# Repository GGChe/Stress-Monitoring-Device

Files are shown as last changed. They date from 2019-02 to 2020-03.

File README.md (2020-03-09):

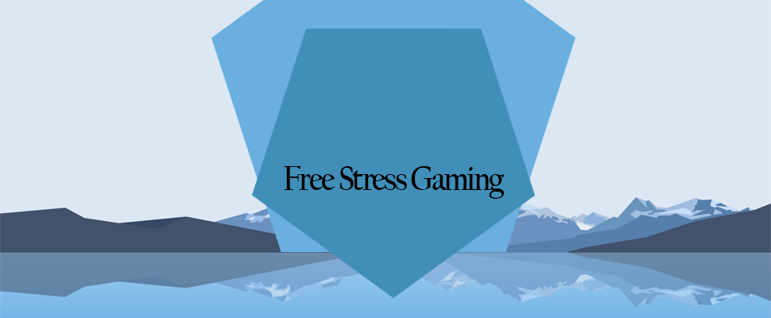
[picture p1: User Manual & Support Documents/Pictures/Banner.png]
StressFree.org Banner





# Welcome to FreeStressGame's open source Project!

Our tream provides an open-source real time embedded project based on the development of a real time biomedical device which aim is to monitor the stress level of a videogame player. This project is open source and anyone is invited to contribute freely sharing all your tips and modifications

## Table of Contents

* [Introduction](#introduction)
* [Methodology](#methodology)
* [Required Components](#required-components)
* [System Manual](#system-manual)
* [Found a Bug](#found-a-bug)
* [Contributing](#contributing)
* [Pubilcation](#publication)
* [SNS](#sns)
* [License](#lisence)

### Introduction

According to the World Health Organisation, mental disorders are a main topic in global health, specially because one in four people in the world will be affected by mental or neurological disorders at some point in their lives. It is estimated that more that 450 million people are currently suffering from such disorders, placing this risk to the top of all the ill-health's causes and disability worldwide. The main mental disorder is depression, and in many situations it is caused by stress. Nowadays, stress is a risk that every person need to face in some point of the day, like work, house, friends, etc. 

There is evidence available that supports the fact that the stress is one of the main triggers of depression. More in detail , such evidence shows that depression can stem from chronic overstimulation of the body's hypothalamic-pituitary-adrenal axis, which produces cortisol in humans. However, while adults can face the stress with therapy and different skills, children are a very enthreaten sector of the population that does not own skills against that. 

With the mentioned before, we can imagine that one of the most risky situations for a child are videogames where we set an unprepared person against a stressfull and addictive situation, causing severe damage on the child. 

Then, this project constitutes a reliable and attractive solution for parents, therapists and adults that want to monitor and control the stress status of the player.

### Methodology
#### [HeartBeat Detection]
The heartbeat measurement technology that we chose for this project is the photopletismography. 
This technique is based on the use of a photodiodethat emits a light pulse in a specific wavelength which, after passing by the blood vessel, the wavelength signal captured by the photosensor changes.  

OUTLINE

According to that change, we can determine whether a pulse of blood has passed in a specific time, depending on our sampling rate.  

#### [Stress Recognition] 
Once the signal is taken, it is carried to the raspberry Pi using a proper wirebased connection to avoid any unwanted interaction with other signals and for a better performance of the device.  
Then, the Raspberry PI will process the data in real time and, at the same time, it will do a basic threshold based control for deciding whether the person is under stress or not. When this process recognize the stress, it makes beep sound for warning. 



### Required Components 
The device consists of the next components:
- Raspberry Pi 3 B+
- PCB adaptor: 
  * 2 X 2Kohm SMD resistors
- Wrist sensor:
  * VEML6030 Light sensor 
  * 1 X IR LED
  * 1 X 1 Kohm SMD resistor 
  * 1 X 10 Kohm SMD resistor
  * 1 X 1000 nF SMD capasitor 
- Piezo Buzzer
- RJ45 Cable
- Finger / Band type case for Wrist sensor
- Raspberry Pi case 

All circuit schematics / PCB Eagle files/ 3D Solidworks files are included in UPLOADED DOCUMENTS. 

### System Description 

#### Hardware section 
In this section you will find useful information of how to replicate our project. Given the components listed before, you need to print the pcb, which files and more deep information is shown in the PCB folder.  

OUTLINE
pin outline
* Connect PCB adaptor with Wrist sensor by RJ45 cable
* Connect PCB adaptor pins with Raspberry Pi pins as shown in below table 

<p align="center">

 
<p align="center">


#### Software section

##### Software setting 
To build our program in your Pi, you need to follow some steps.  

```
sudo apt-get update

git clone https://github.com/GGChe/Stress_Controller_Device
```
You would need to update and install the libraries of PHP5.6, Apache2 and compilers if your are working on a vanilla version of the OS.

```
sudo apt-get install php5.6

sudo apt-get install apache2

sudo apt-get install g++
```
If you have any problem installing php5.6 in Raspbian, cause it is not very well supported, follow this guide:
https://unnikked.ga/how-to-install-php-5-6-on-a-raspberry-pi-2-5fd93879cb14

##### Driver 
We developed a driver for the VEML6030 sensor, that uses I2C communication protocol, using the data obtained from the link below. The driver given in that project was initially prepared for Arduino but we had to modify it completely to make it run in every system using a proper c++ code.

[Mbed VEML6030 Driver](https://os.mbed.com/teams/MSS/code/VEML6030/)

##### Compilation from source

To compile the whole code, you only need to go to the code's folder and type on the terminal

```
cmake .

make 

sudo ./StressC.out
```

To run the program from the boot of the system

```
sudo nano /etc/rc.local

```

And then, write before "exit 0" the following scrypt:

```
sudo ./PATH/StressC.out

```

### Found a bug?

Bugs can be reported at: https://github.com/GGChe/Stress_Controller_Device/issues

Please try the latest release build before reporting, be sure to also include any logs or steps to reproduce you may have, as well as your Forge version, and whether or not you are using a third party loader such as Cauldron. When submitting logs please use a service such as Pastebin, do not paste the log directly into the issue.

### Contributing

Ahmed Elmogamer 
* Main role: Software Engineer 
* Specific tasks 
  : Coding the main program and making sensors' driver.  

Daewon Jung  
* Main role: Mechanical Engineer 
* Specific tasks 
  : Designing cases, assist making PCB and Promotion. 
  
Gabriel Galeote Checa 
* Main role: Electronic Engineer 
* Specific tasks 
  : Designing PCB and Website architecture development, Fabrication and Soldering of the PCB. 
  
### Publication
Check our publication in Hackaday.

[](https://hackaday.io/project/164972-free-stress-gaming)

### SNS 
In our socialmedia you can find some demos and video explanations of how the system works. 

[](https://www.youtube.com/channel/UC1Y8QuR_0B8nRpyRaub2-ag)

[](https://www.instagram.com/free_stress_gaming/)

Check our two youtube videos explaining how the system works!
- https://www.youtube.com/watch?v=JRjO4hhqV6E
- https://www.youtube.com/watch?v=9uvpTM_b6e0&t=2s
### Credits

This project used the current driver uploaded in mbed for other purposes, we fixed some errors for the VEML6030 use in RPI and we had to recode some sections of the driver.

We also wannt to thanks our mate Cheng who was really helpful in the lab.

### License

The MIT License

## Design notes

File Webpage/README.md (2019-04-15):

# Website

## How does the webpage works?

We have developed a webpage architecture that is going to be the configuration interface between the user and the device. By login in the website and using the resources available in it the user is able to modify the parameters of their profile by the proposed calibration. 

The webpage main feature is to initialise the device and all the configuration needed for that as well as identify the user too have more than one user on the same device. Thus, if we load one user, we will be using that user all the time until we connect the device to internet and we change the user to other one.

The methodology is the following one:

- The first time you enter in the webpage you would need to signup. That will automatically generate a "login.txt" file on the /var/www/html/Project folder of the RPI. From here, all the files generated will be storaged on the same folder.

- Once the user is created and registered, the webpage will 
create an "user.txt" where it will set the user that is already registered.

- The first time that a user is signed up, it will appear the calibration webpage that is going to interact with the RPI to measure the Heart Rate Average of the user during the tasks required. 

- After the calibration, that can be done only the first time you log in or in your profile page, we go to the session webpage. In this webpage you have the possibility of recalibrate the sensor. If not, we go to the Session webpage.

- In the Session webpage, we can manually run the sensor by using the button provided.

That is everything! There you have a demo video of how to use the webpage architecture created!

[](https://www.youtube.com/watch?v=9uvpTM_b6e0&t=1s)

## How to install the webpage files

First, check that you have the correct packages for running php and apache server. For that, run the next commands on the terminal:

```
sudo apt-get update

sudo apt-get install apache 2
```

If you are using raspbian, you need to find the right package for php5.6 that is not really supported in Raspbian. Follow the next webpage steps to install it properly:

- https://unnikked.ga/how-to-install-php-5-6-on-a-raspberry-pi-2-5fd93879cb1

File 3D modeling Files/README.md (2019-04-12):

## 3D modeling cases for Strerss Controller 
To consider about the product's usability, PCB and Raspberry Pi cases are desinged by 'Solid Works', and rendered by 'KeyShot8'.  

## PCB_CASE
Depend on the user's preference, 'Watch type' or 'Finger type' case can be chosen for Sensor PCB. 

* Watch Type Case
<p align="center">
  
</p>
<p align="center">
  
</p>

* Finger Type Case
<p align="center">
  
</p>

## Raspberry-Pi CASE - Top 
Top case is desinged by below criteria: 
* This case should have enough holes for cooling.  
* This case should have appealing design for promotion 

<p align="center">
  
</p>
<p align="center">
  
</p>

## Raspberry-Pi CASE - Bottom 
Bottom case should be considered about ports for 'power cable' and 'SD-card'. 

<p align="center">
  
</p>

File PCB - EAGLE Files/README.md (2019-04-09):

# Electronic Design

This project consists of 2 main Printec Circuit Boards (PCB)pcbs: RPI adaptor and Sensor PCb.

The feature of the RPI adaptor pcb is to connect the correct RPI pines to the sensor circuit that we are using. We need to guide all the signal through a RJ45 cable that is going to the sensor pcb. Thus, it is need to adapt and guide signal in the correct order. 

The pcbs are shown below:
<p align="center">


<p align="center">


All the components that we are using on the PCB are Surface Mount Devices (SMD) and therefore, we should need a reflow oven to solder them, even though youu can solder everything by hang if you are skilled enough.

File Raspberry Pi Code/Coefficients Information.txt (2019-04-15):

The coefficients used were produced by a python code that utilized:

signal.firwin(801, [0.2, 10], pass_zero = 0, fs = 200)

This produces coefficients with the following specifications:

Taps: 801
lower frequency: 0.2 Hz
High frequency: 10 Hz
type of filter: Band Pass
Frequency: 200 Hz

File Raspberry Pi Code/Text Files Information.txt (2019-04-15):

An explanation of the text files:

status.txt:

0 - if the user is on the log in page
1 - if the user enters the Session page
2 - if the user enters the Sign up

username.txt:

Ahmed - has the current username being used whether when logged in or during configuration

userdata.txt:

Ahmed/23/43/13
Gabri/34/53/23
Daewon/43/54/54

Has a list of all the users and their rest, run and stress. 
These values have to be of 2 digits.

exit.txt:

0 - stay in current page
1 - return to main menu

session.txt:

After the user logs in

0 - do not read the sensor
1 - read the sensor and detect stress

config.txt:

During configuration

0 - do not read and wait for user's confirmation
1 - read and calculate required average "rest or run"

white.txt:

used by RPI to output the detected white signals

eventlog.txt:

Writes the log of all the stress events recorded.

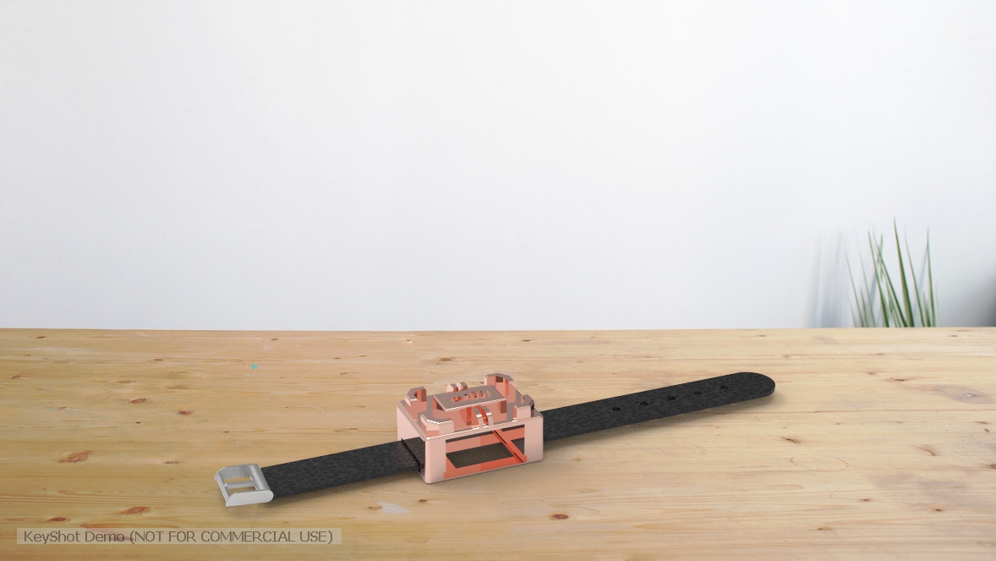
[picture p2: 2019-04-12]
3D modeling Files/keyshot/PCBcase1.jpg

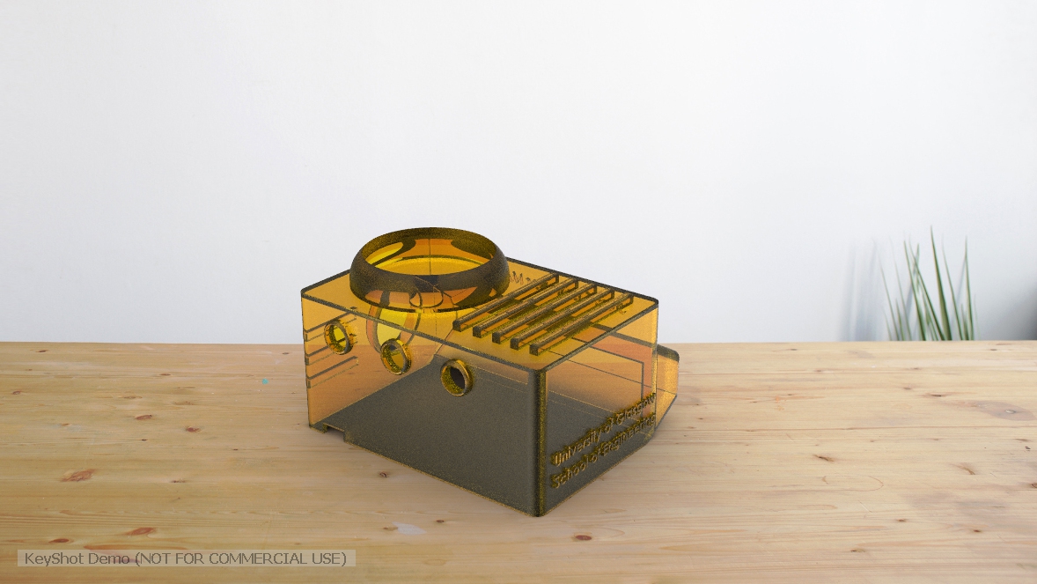
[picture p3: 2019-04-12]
3D modeling Files/keyshot/Topcase2.jpg

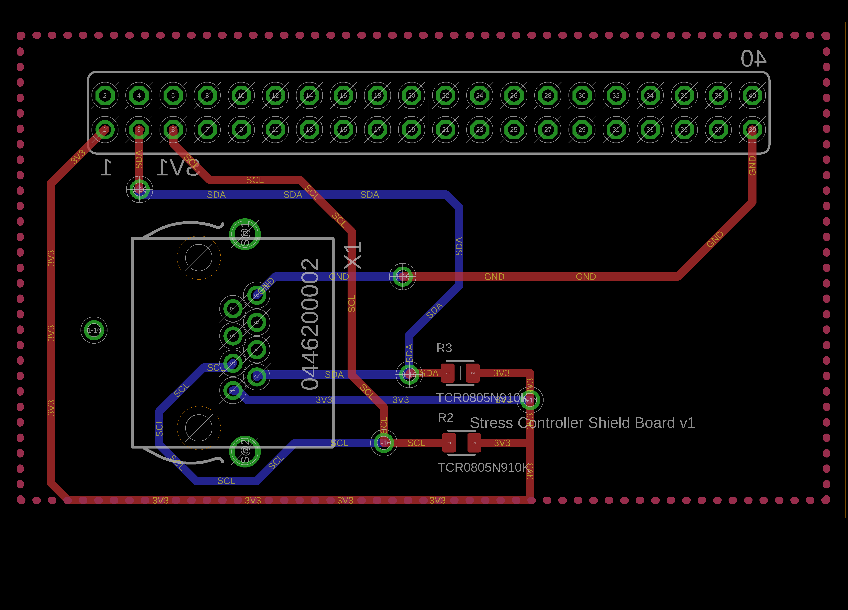
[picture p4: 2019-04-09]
PCB - EAGLE Files/Models/PCB_RPI/RPI-PCB.png

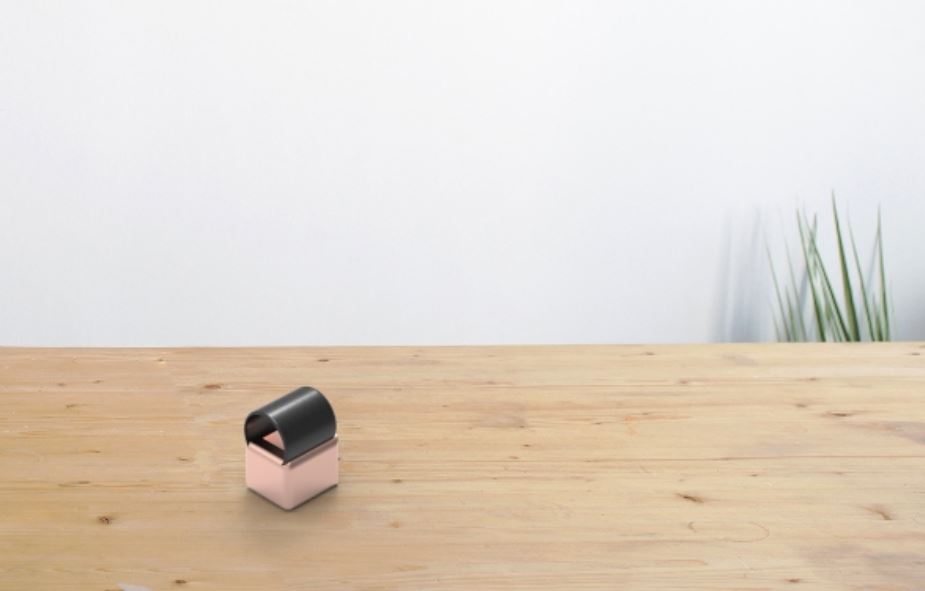
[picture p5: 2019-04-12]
3D modeling Files/keyshot/Fingertype.JPG

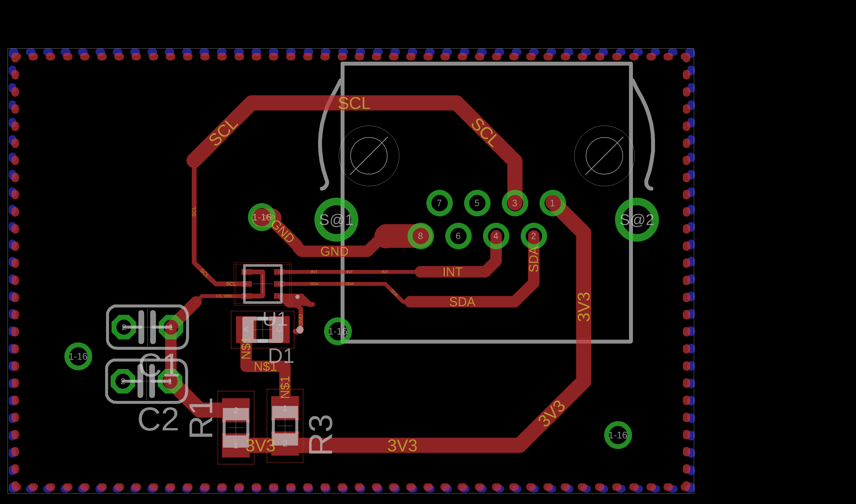
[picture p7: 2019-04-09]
PCB - EAGLE Files/Models/PCB_Sensor/SENSOR-PCB.png

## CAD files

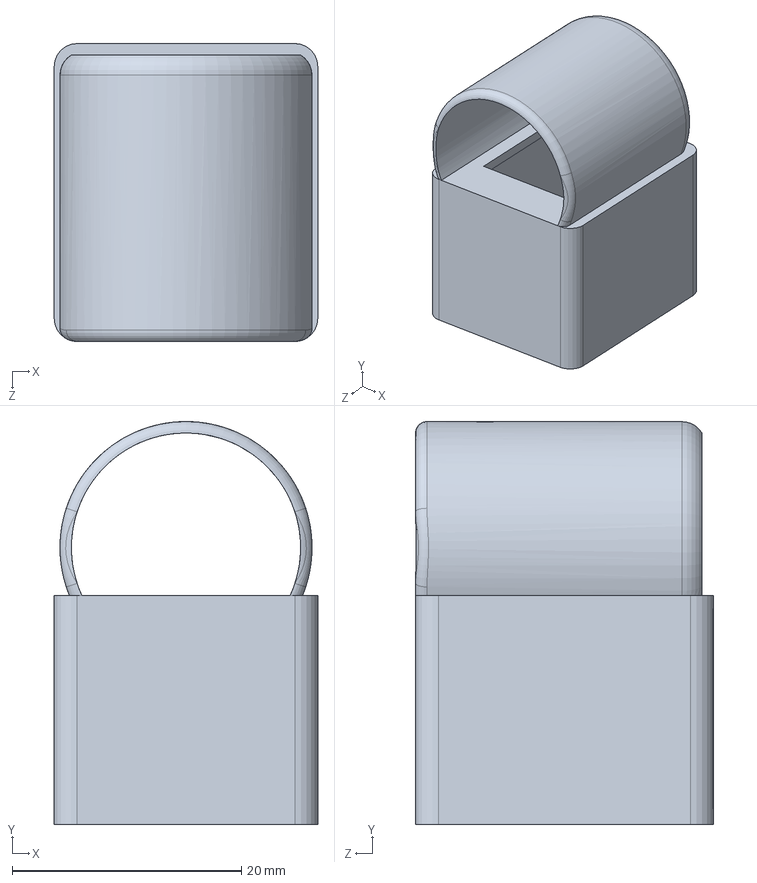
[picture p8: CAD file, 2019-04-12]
3D modeling Files/Finger_Type_CASE.SLDPRT
23.0 x 35.2 x 26.0 mm

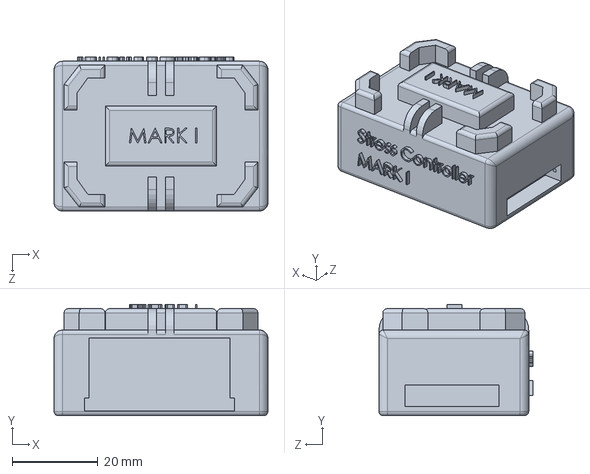
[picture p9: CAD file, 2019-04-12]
3D modeling Files/Watch_Type_CASE.SLDPRT
50.0 x 26.0 x 36.0 mm

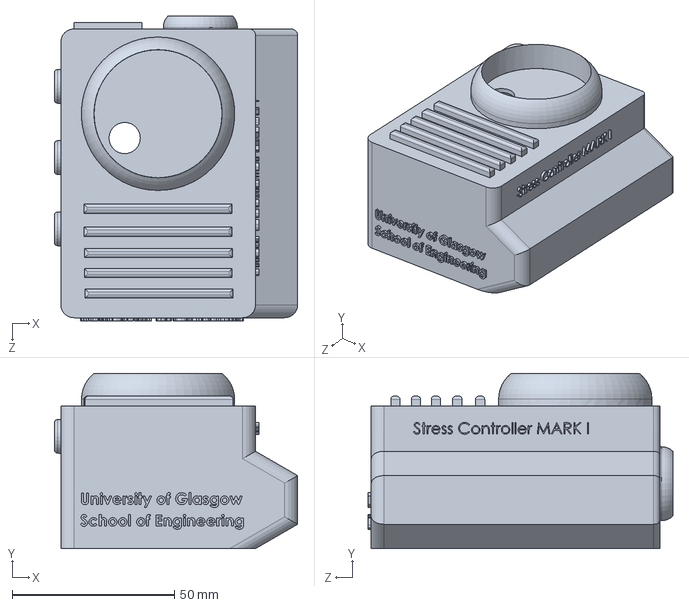
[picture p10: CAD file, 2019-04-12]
3D modeling Files/Raspberry_Pi_TOP CASE.SLDPRT
75.0 x 54.0 x 94.0 mm

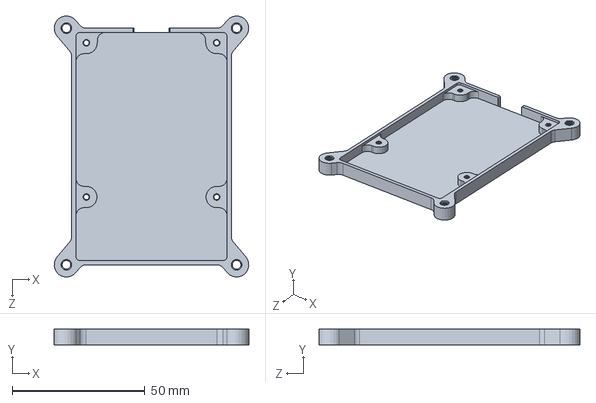
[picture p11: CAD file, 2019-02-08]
3D modeling Files/BOTTOM CASE.SLDPRT
73.2 x 6.01 x 98.2 mm

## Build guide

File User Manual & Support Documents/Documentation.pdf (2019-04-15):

## Stress Controller Device C++ Code

Generated by Doxygen 1.8.15

i

1 Hierarchical Index | 1
2 Class Index | 3
3 File Index | 5
4 Class Documentation | 7

Generated by Doxygen

ii

5 File Documentation | 19

iii

iv

Index | 33

# Chapter 1

# Hierarchical Index

## 1.1 Class Hierarchy

This inheritance list is sorted roughly, but not completely, alphabetically:

CppTimer | 7
ObtainData | 12
Fir1 | | 8
VEML6030rpi | | 13

### 2 Hierarchical Index

# Chapter 2

# Class Index

## 2.1 Class List

Here are the classes, structs, unions and interfaces with brief descriptions:

### 4 Class Index

# Chapter 3

# File Index

## 3.1 File List

Here is a list of all files with brief descriptions:

### 6 File Index

# Chapter 4

# Class Documentation

## 4.1 CppTimer Class Reference

#include <CppTimer.h>

Inheritance diagram for CppTimer:

CppTimer

ObtainData

Public Member Functions

- CppTimer ()
- virtual ∼CppTimer ()
- void start (long nanosecs)
- virtual void timerEvent ()=0

### 4.1.1 Constructor & Destructor Documentation

### 4.1.1.1 CppTimer()

CppTimer::CppTimer ( ) [inline]

4.1.1.2 ∼CppTimer()

virtual CppTimer::∼CppTimer ( ) [inline], [virtual]

### 8 Class Documentation

### 4.1.2 Member Function Documentation

### 4.1.2.1 start()

void CppTimer::start (

long nanosecs ) [inline]

### 4.1.2.2 timerEvent()

virtual void CppTimer::timerEvent ( ) [pure virtual]

The documentation for this class was generated from the following file:

- C:/Users/Mufasa/Desktop/123/Final_V3/CppTimer.h

## 4.2 Fir1 Class Reference

#include <Fir1.h>

Public Member Functions

- template<unsigned nTaps>
Fir1 (const double(&_coefficients)[nTaps])
- Fir1 (double ∗coefficients, unsigned number_of_taps)
- Fir1 (const char ∗coeffFile, unsigned number_of_taps=0)
- Fir1 (unsigned number_of_taps)
- ∼Fir1 ()
- double filter (double input)
- void lms_update (double error)
- void setLearningRate (double _mu)
- double getLearningRate ()
- void reset ()
- void zeroCoeff ()
- unsigned getTaps ()
- double getTapInputPower ()

### 4.2.1 Detailed Description

Finite impulse response filter. The precision is double. It takes as an input a file with coefficients or an double array.

4.2 Fir1 Class Reference | 9

### 4.2.2 Constructor & Destructor Documentation

### 4.2.2.1 Fir1() [1/4]

template<unsigned nTaps>

Fir1::Fir1 (

const double(&) _coefficients[nTaps] ) [inline]

Coefficients as a const double array. Because the array is const the number of taps is identical to the length of the array.

### 10 Class Documentation

Parameters

_coefficients A const double array with the impulse response.

### 4.2.2.2 Fir1() [2/4]

Fir1::Fir1 (

double ∗ coefficients,

unsigned number_of_taps )

Coefficients as a (non-constant-) double array where the length needs to be specified.

Parameters

coefficients | Coefficients as double array.
number_of_taps | Number of taps (needs to match the number of coefficients

### 4.2.2.3 Fir1() [3/4]

Fir1::Fir1 (

const char ∗ coeffFile,

unsigned number_of_taps = 0 )

Coefficients as a text file (for example from Python) The number of taps is automatically detected when the taps are kept zero.

Parameters

coeffFile | Patht to textfile where every line contains one coefficient
number_of_taps | Number of taps (0 = autodetect)

### 4.2.2.4 Fir1() [4/4]

Fir1::Fir1 (

unsigned number_of_taps )

Inits all coefficients and the buffer to zero

This is useful for adaptive filters where we start with zero valued coefficients.

4.2 Fir1 Class Reference | 11

4.2.2.5 ∼Fir1()

Fir1::∼Fir1 ( )

Releases the coefficients and buffer.

### 4.2.3 Member Function Documentation

### 4.2.3.1 filter()

double Fir1::filter (

double input )

The actual filter function operation: it receives one sample and returns one sample.

Parameters

input The input sample.

### 4.2.3.2 getLearningRate()

double Fir1::getLearningRate ( ) [inline]

Getting the learning rate for the adaptive filter.

### 4.2.3.3 getTapInputPower()

double Fir1::getTapInputPower ( )

Returns the power of the of the buffer content:

sum_k buffer[k]∧2 which is needed to implement a normalised LMS algorithm.

### 4.2.3.4 getTaps()

unsigned Fir1::getTaps ( ) [inline]

Returns the number of taps.

### 4.2.3.5 lms_update()

void Fir1::lms_update (

double error )

LMS adaptive filter weight update:

Every filter coefficient is updated with: w_k(n+1) = w_k(n) + learning_rate ∗ buffer_k(n) ∗ error(n)

### 12 Class Documentation

Parameters

error Is the term error(n), the error which adjusts the FIR conefficients.

### 4.2.3.6 reset()

void Fir1::reset ( )

Resets the buffer (but not the coefficients)

### 4.2.3.7 setLearningRate()

void Fir1::setLearningRate (

double _mu ) [inline]

Setting the learning rate for the adaptive filter.

Parameters

_mu The learning rate (i.e. rate of the change by the error signal)

### 4.2.3.8 zeroCoeff()

void Fir1::zeroCoeff ( )

Sets all coefficients to zero

The documentation for this class was generated from the following files:

- C:/Users/Mufasa/Desktop/123/Final_V3/Fir1.h
- C:/Users/Mufasa/Desktop/123/Final_V3/Fir1.cpp

## 4.3 ObtainData Class Reference

Inheritance diagram for ObtainData:

ObtainData

CppTimer

4.4 VEML6030rpi Class Reference | 13

Additional Inherited Members

The documentation for this class was generated from the following file:

- C:/Users/Mufasa/Desktop/123/Final_V3/StressController.cpp

## 4.4 VEML6030rpi Class Reference

#include <VEML6030rpi.h>

Public Member Functions

- VEML6030rpi ()
- virtual ∼VEML6030rpi ()
- void init (uint8_t _ADR)
- void setALS (uint16_t cmd)
- void setALS_WH (uint16_t wh)
- void setALS_WL (uint16_t wl)
- uint8_t SetIntTime (uint16_t TimeBits)
- uint8_t SetGain (uint16_t GainVal)
- uint16_t getALS (void)
- uint16_t getWhite (void)
- uint16_t getALS_INT (void)
- unsigned int IntTime2Bits (unsigned int Time)
- uint16_t Gain2Bits (float GainVal)
- void powerSaving (uint16_t ps)
- uint8_t Shutdown (void)
- uint8_t PowerOn (void)
- void SetResolution (float Gain, float IntTime)
- void AutoSet (void)

Public Attributes

- uint16_t als
- uint16_t white
- float resolution
- float lux
- float whitelux

### 4.4.1 Constructor & Destructor Documentation

### 4.4.1.1 VEML6030rpi()

VEML6030rpi::VEML6030rpi ( )

### 14 Class Documentation

4.4.1.2 ∼VEML6030rpi()

VEML6030rpi::∼VEML6030rpi ( ) [virtual]

### 4.4.2 Member Function Documentation

### 4.4.2.1 AutoSet()

void VEML6030rpi::AutoSet (

void )

### 4.4.2.2 Gain2Bits()

uint16_t VEML6030rpi::Gain2Bits (

float GainVal )

### 4.4.2.3 getALS()

uint16_t VEML6030rpi::getALS (

void )

### 4.4.2.4 getALS_INT()

uint16_t VEML6030rpi::getALS_INT (

void )

### 4.4.2.5 getWhite()

uint16_t VEML6030rpi::getWhite (

void )

4.4 VEML6030rpi Class Reference | 15

### 4.4.2.6 init()

void VEML6030rpi::init (

uint8_t _ADR )

### 4.4.2.7 IntTime2Bits()

unsigned int VEML6030rpi::IntTime2Bits (

unsigned int Time )

### 4.4.2.8 PowerOn()

uint8_t VEML6030rpi::PowerOn (

void )

### 4.4.2.9 powerSaving()

void VEML6030rpi::powerSaving (

uint16_t ps )

### 4.4.2.10 setALS()

void VEML6030rpi::setALS (

uint16_t cmd )

### 4.4.2.11 setALS_WH()

void VEML6030rpi::setALS_WH (

uint16_t wh )

### 4.4.2.12 setALS_WL()

void VEML6030rpi::setALS_WL (

uint16_t wl )

### 16 Class Documentation

### 4.4.2.13 SetGain()

uint8_t VEML6030rpi::SetGain (

uint16_t GainVal )

### 4.4.2.14 SetIntTime()

uint8_t VEML6030rpi::SetIntTime (

uint16_t TimeBits )

### 4.4.2.15 SetResolution()

void VEML6030rpi::SetResolution (

float Gain,

float IntTime )

### 4.4.2.16 Shutdown()

uint8_t VEML6030rpi::Shutdown (

void )

### 4.4.3 Member Data Documentation

### 4.4.3.1 als

uint16_t VEML6030rpi::als

### 4.4.3.2 lux

float VEML6030rpi::lux

4.4 VEML6030rpi Class Reference | 17

### 4.4.3.3 resolution

float VEML6030rpi::resolution

### 4.4.3.4 white

uint16_t VEML6030rpi::white

### 4.4.3.5 whitelux

float VEML6030rpi::whitelux

The documentation for this class was generated from the following files:

- C:/Users/Mufasa/Desktop/123/Final_V3/VEML6030rpi.h
- C:/Users/Mufasa/Desktop/123/Final_V3/VEML6030rpi.cpp

### 18 Class Documentation

# Chapter 5

# File Documentation

## 5.1 C:/Users/Mufasa/Desktop/123/Final_V3/CppTimer.h File Reference

#include <stdlib.h>

#include <unistd.h>

#include <stdio.h>

#include <signal.h>

#include <time.h>

Classes

- class CppTimer

Macros

- #define CLOCKID CLOCK_MONOTONIC
- #define SIG SIGRTMIN

### 5.1.1 Macro Definition Documentation

### 5.1.1.1 CLOCKID

#define CLOCKID CLOCK_MONOTONIC

GNU GENERAL PUBLIC LICENSE Version 3, 29 June 2007

(C) 2018, Bernd Porr mail@bernporr.me.uk

This is inspired by the timer_create man page.

### 20 File Documentation

### 5.1.1.2 SIG

#define SIG SIGRTMIN

## 5.2 C:/Users/Mufasa/Desktop/123/Final_V3/Fir1.cpp File Reference

#include "Fir1.h"

#include <string.h>

#include <stdlib.h>

#include <assert.h>

#include <stdexcept>

## 5.3 C:/Users/Mufasa/Desktop/123/Final_V3/Fir1.h File Reference

#include <stdio.h>

Classes

- class Fir1

## 5.4 C:/Users/Mufasa/Desktop/123/Final_V3/StressController.cpp File Reference

#include "VEML6030rpi.h"

#include <wiringPiI2C.h>

#include "Fir1.h"

#include "CppTimer.h"

#include <fstream>

#include <array>

#include <time.h>

#include <string>

#include <unistd.h>

#include <bits/stdc++.h>

#include <iostream>

#include <stdio.h>

#include <errno.h>

#include <wiringPi.h>

#include <softTone.h>

Classes

- class ObtainData

5.4 C:/Users/Mufasa/Desktop/123/Final_V3/StressController.cpp File Reference | 21

Macros

- #define PIN 7

Functions

- void startalarm ()
- void alarm ()
- void init ()
- int main (void)

Variables

- int ipulse = 0
- int statpulse = 0
- int pd = 0
- int tempbpm = 80
- int iuserrest
- int iuserrun
- int iuserstress
- int tbpm
- int pbpm
- int configstep = 1
- int cnt = 1
- int scale [14] = {659, 659, 0, 659, 0, 523, 659, 0, 784, 0, 0, 0, 392, 0}
- int configstat = 1
- double restctr = 0
- double runctr = 0
- double runT = 0
- double restT = 0
- double ctr = 0
- double pulse [300] = {0}
- double mpulse = 0
- double duserrest
- double duserrun
- double duserstress
- VEML6030rpi veml6030
- string status
- string username
- string myexit
- string session
- string config
- int sessionbpm [20] = {0, 100, 200, 300, 400, 500, 600, 700, 800, 900, 1000, 2000, 3000, 4000, 5000, 6000, 7000, 8000, 9000, 10000}
- Fir1 fir ("coeffnoise.dat", 801)
- bool userfound = false
- ifstream statustxt
- string statusfname = "/var/www/html/Project/status.txt"
- ifstream usernametxt
- string usernamefname = "/var/www/html/Project/username.txt"
- fstream userstxt
- string usersfname = "/var/www/html/Project/userdata.txt"
- ifstream exittxt

### 22 File Documentation

- string exitfname = "/var/www/html/Project/exit.txt"
- ifstream sessiontxt
- string sessionfname = "/var/www/html/Project/session.txt"
- ifstream configtxt
- string configfname = "/var/www/html/Project/config.txt"
- ofstream whitetxt
- string whitefname = "/var/www/html/Project/white.txt"
- ofstream eventlogtxt
- string eventlogfname = "/var/www/html/Project/eventlog.txt"

### 5.4.1 Macro Definition Documentation

### 5.4.1.1 PIN

#define PIN 7

"Monitoring of stress level" University of Glasgow Supervised by: Bernd Porr By Ahmed Elmogamer, Daewon Jung and Gabriel Galeote Checa

Official project location: https://github.com/GGChe/Stress_Controller_Device

Open Readme for details about the project

Permission is hereby granted, free of charge, to any person obtaining a copy of this software and associated documentation files (the "Software"), to deal in the Software without restriction, including without limitation the rights to use, copy, modify, merge, publish, distribute, sublicense, and/or sell copies of the Software, and to permit persons to whom the Software is furnished to do so, subject to the following conditions:

The above copyright notice and this permission notice shall be included in all copies or substantial portions of the Software.

THE SOFTWARE IS PROVIDED "AS IS", WITHOUT WARRANTY OF ANY KIND, EXPRESS OR IMPLIED, IN←-CLUDING BUT NOT LIMITED TO THE WARRANTIES OF MERCHANTABILITY, FITNESS FOR A PARTICULAR PURPOSE AND NONINFRINGEMENT. IN NO EVENT SHALL THE AUTHORS OR COPYRIGHT HOLDERS BE LIABLE FOR ANY CLAIM, DAMAGES OR OTHER LIABILITY, WHETHER IN AN ACTION OF CONTRACT, TORT OR OTHERWISE, ARISING FROM, OUT OF OR IN CONNECTION WITH THE SOFTWARE OR THE USE OR OTHER DEALINGS IN THE SOFTWARE.

### 5.4.2 Function Documentation

### 5.4.2.1 alarm()

void alarm ( )

5.4 C:/Users/Mufasa/Desktop/123/Final_V3/StressController.cpp File Reference | 23

### 5.4.2.2 init()

void init ( )

### 5.4.2.3 main()

int main (

void )

Firstly, we need to check whether status is 0, 1 or 2. Then, if status is equals to 0, we are in the main webpage. if status is equals to 1, we are logged but the user already exists to we don't need to calibrate if status is equals to 2, we need to signup and calibrate.

### 5.4.2.4 startalarm()

void startalarm ( )

### 5.4.3 Variable Documentation

### 5.4.3.1 cnt

int cnt = 1

### 5.4.3.2 config

string config

### 5.4.3.3 configfname

string configfname = "/var/www/html/Project/config.txt"

### 5.4.3.4 configstat

int configstat = 1

### 24 File Documentation

### 5.4.3.5 configstep

int configstep = 1

### 5.4.3.6 configtxt

ifstream configtxt

### 5.4.3.7 ctr

double ctr = 0

### 5.4.3.8 duserrest

double duserrest

### 5.4.3.9 duserrun

double duserrun

### 5.4.3.10 duserstress

double duserstress

### 5.4.3.11 eventlogfname

string eventlogfname = "/var/www/html/Project/eventlog.txt"

### 5.4.3.12 eventlogtxt

ofstream eventlogtxt

5.4 C:/Users/Mufasa/Desktop/123/Final_V3/StressController.cpp File Reference | 25

### 5.4.3.13 exitfname

string exitfname = "/var/www/html/Project/exit.txt"

### 5.4.3.14 exittxt

ifstream exittxt

### 5.4.3.15 fir

Fir1 fir("coeffnoise.dat", 801)

### 5.4.3.16 ipulse

int ipulse = 0

### 5.4.3.17 iuserrest

int iuserrest

### 5.4.3.18 iuserrun

int iuserrun

### 5.4.3.19 iuserstress

int iuserstress

### 5.4.3.20 mpulse

double mpulse = 0

### 26 File Documentation

### 5.4.3.21 myexit

string myexit

### 5.4.3.22 pbpm

int pbpm

### 5.4.3.23 pd

int pd = 0

### 5.4.3.24 pulse

double pulse[300] = {0}

### 5.4.3.25 restctr

double restctr = 0

### 5.4.3.26 restT

double restT = 0

### 5.4.3.27 runctr

double runctr = 0

### 5.4.3.28 runT

double runT = 0

5.4 C:/Users/Mufasa/Desktop/123/Final_V3/StressController.cpp File Reference | 27

### 5.4.3.29 scale

int scale[14] = {659, 659, 0, 659, 0, 523, 659, 0, 784, 0, 0, 0, 392, 0}

### 5.4.3.30 session

string session

### 5.4.3.31 sessionbpm

int sessionbpm[20] = {0, 100, 200, 300, 400, 500, 600, 700, 800, 900, 1000, 2000, 3000, 4000,

5000, 6000, 7000, 8000, 9000, 10000}

### 5.4.3.32 sessionfname

string sessionfname = "/var/www/html/Project/session.txt"

### 5.4.3.33 sessiontxt

ifstream sessiontxt

### 5.4.3.34 statpulse

int statpulse = 0

### 5.4.3.35 status

string status

### 28 File Documentation

### 5.4.3.36 statusfname

string statusfname = "/var/www/html/Project/status.txt"

### 5.4.3.37 statustxt

ifstream statustxt

### 5.4.3.38 tbpm

int tbpm

### 5.4.3.39 tempbpm

int tempbpm = 80

### 5.4.3.40 userfound

bool userfound = false

### 5.4.3.41 username

string username

### 5.4.3.42 usernamefname

string usernamefname = "/var/www/html/Project/username.txt"

### 5.4.3.43 usernametxt

ifstream usernametxt

5.5 C:/Users/Mufasa/Desktop/123/Final_V3/VEML6030rpi.cpp File Reference | 29

### 5.4.3.44 usersfname

string usersfname = "/var/www/html/Project/userdata.txt"

### 5.4.3.45 userstxt

fstream userstxt

### 5.4.3.46 veml6030

VEML6030rpi veml6030

### 5.4.3.47 whitefname

string whitefname = "/var/www/html/Project/white.txt"

### 5.4.3.48 whitetxt

ofstream whitetxt

## 5.5 C:/Users/Mufasa/Desktop/123/Final_V3/VEML6030rpi.cpp File Reference

#include "VEML6030rpi.h"

#include <wiringPiI2C.h>

#include <fstream>

#include <math.h>

#include <iostream>

### 30 File Documentation

Macros

- #define _ADR 0x48
- #define ALS_CONF 0x00
- #define ALS_WH 0x01
- #define ALS_WL 0x02
- #define PWR_SVG 0x03
- #define ALS_CMD 0x04
- #define WHITE_CMD 0x05
- #define ALS_INT 0x06
- #define IT25 0x300
- #define IT50 0x200
- #define IT100 0x000
- #define IT200 0x040
- #define IT400 0x080
- #define IT800 0x0C0
- #define GAIN_1 0x0000
- #define GAIN_2 0x0800
- #define GAIN_1_8 0x1000
- #define GAIN_1_4 0x1800

### 5.5.1 Macro Definition Documentation

### 5.5.1.1 _ADR

#define _ADR 0x48

### 5.5.1.2 ALS_CMD

#define ALS_CMD 0x04

### 5.5.1.3 ALS_CONF

#define ALS_CONF 0x00

### 5.5.1.4 ALS_INT

#define ALS_INT 0x06

5.5 C:/Users/Mufasa/Desktop/123/Final_V3/VEML6030rpi.cpp File Reference | 31

### 5.5.1.5 ALS_WH

#define ALS_WH 0x01

### 5.5.1.6 ALS_WL

#define ALS_WL 0x02

### 5.5.1.7 GAIN_1

#define GAIN_1 0x0000

### 5.5.1.8 GAIN_1_4

#define GAIN_1_4 0x1800

### 5.5.1.9 GAIN_1_8

#define GAIN_1_8 0x1000

### 5.5.1.10 GAIN_2

#define GAIN_2 0x0800

### 5.5.1.11 IT100

#define IT100 0x000

### 5.5.1.12 IT200

#define IT200 0x040

### 32 File Documentation

### 5.5.1.13 IT25

#define IT25 0x300

### 5.5.1.14 IT400

#define IT400 0x080

### 5.5.1.15 IT50

#define IT50 0x200

### 5.5.1.16 IT800

#define IT800 0x0C0

### 5.5.1.17 PWR_SVG

#define PWR_SVG 0x03

### 5.5.1.18 WHITE_CMD

#define WHITE_CMD 0x05

## 5.6 C:/Users/Mufasa/Desktop/123/Final_V3/VEML6030rpi.h File Reference

#include <unistd.h>

#include <fcntl.h>

#include <string>

#include <fstream>

#include <sys/ioctl.h>

#include <linux/i2c-dev.h> #include <stdio.h>

#include <iostream>

Classes

- class VEML6030rpi

# Index

_ADR
VEML6030rpi.cpp, 30
∼CppTimer
CppTimer, 7
∼Fir1
Fir1, 10
∼VEML6030rpi
VEML6030rpi, 13

alarm
StressController.cpp, 22
als
VEML6030rpi, 16
ALS_CMD
VEML6030rpi.cpp, 30
ALS_CONF
VEML6030rpi.cpp, 30
ALS_INT
VEML6030rpi.cpp, 30
ALS_WH
VEML6030rpi.cpp, 30
ALS_WL
VEML6030rpi.cpp, 31
AutoSet
VEML6030rpi, 14

C:/Users/Mufasa/Desktop/123/Final_V3/CppTimer.h, 19 C:/Users/Mufasa/Desktop/123/Final_V3/Fir1.cpp, 20 C:/Users/Mufasa/Desktop/123/Final_V3/Fir1.h, 20 C:/Users/Mufasa/Desktop/123/Final_V3/StressController.cpp, 20
C:/Users/Mufasa/Desktop/123/Final_V3/VEML6030rpi.cpp, 29
C:/Users/Mufasa/Desktop/123/Final_V3/VEML6030rpi.h, 32
CLOCKID
CppTimer.h, 19
cnt
StressController.cpp, 23
config
StressController.cpp, 23
configfname
StressController.cpp, 23
configstat
StressController.cpp, 23
configstep
StressController.cpp, 23
configtxt
StressController.cpp, 24
CppTimer, 7

∼CppTimer, 7
CppTimer, 7
start, 8
timerEvent, 8
CppTimer.h
CLOCKID, 19
SIG, 19
ctr
StressController.cpp, 24

duserrest
StressController.cpp, 24
duserrun
StressController.cpp, 24
duserstress
StressController.cpp, 24

eventlogfname
StressController.cpp, 24
eventlogtxt
StressController.cpp, 24
exitfname
StressController.cpp, 24
exittxt
StressController.cpp, 25

filter
Fir1, 11
fir
StressController.cpp, 25
Fir1, 8
∼Fir1, 10
filter, 11
Fir1, 9, 10
getLearningRate, 11
getTapInputPower, 11
getTaps, 11
lms_update, 11
reset, 12
setLearningRate, 12
zeroCoeff, 12

Gain2Bits
VEML6030rpi, 14
GAIN_1
VEML6030rpi.cpp, 31
GAIN_1_4
VEML6030rpi.cpp, 31
GAIN_1_8
VEML6030rpi.cpp, 31

### 34 INDEX

GAIN_2
VEML6030rpi.cpp, 31
getALS
VEML6030rpi, 14
getALS_INT
VEML6030rpi, 14
getLearningRate
Fir1, 11
getTapInputPower
Fir1, 11
getTaps
Fir1, 11
getWhite
VEML6030rpi, 14

init
StressController.cpp, 22
VEML6030rpi, 14
IntTime2Bits
VEML6030rpi, 15
ipulse
StressController.cpp, 25
IT100
VEML6030rpi.cpp, 31
IT200
VEML6030rpi.cpp, 31
IT25
VEML6030rpi.cpp, 31
IT400
VEML6030rpi.cpp, 32
IT50
VEML6030rpi.cpp, 32
IT800
VEML6030rpi.cpp, 32
iuserrest
StressController.cpp, 25
iuserrun
StressController.cpp, 25
iuserstress
StressController.cpp, 25

lms_update
Fir1, 11
lux
VEML6030rpi, 16

main
StressController.cpp, 23
mpulse
StressController.cpp, 25
myexit
StressController.cpp, 25

ObtainData, 12

pbpm
StressController.cpp, 26
pd
StressController.cpp, 26

PIN
StressController.cpp, 22
PowerOn
VEML6030rpi, 15
powerSaving
VEML6030rpi, 15
pulse
StressController.cpp, 26
PWR_SVG
VEML6030rpi.cpp, 32

reset
Fir1, 12
resolution
VEML6030rpi, 16
restctr
StressController.cpp, 26
restT
StressController.cpp, 26
runctr
StressController.cpp, 26
runT
StressController.cpp, 26

scale
StressController.cpp, 26
session
StressController.cpp, 27
sessionbpm
StressController.cpp, 27
sessionfname
StressController.cpp, 27
sessiontxt
StressController.cpp, 27
setALS
VEML6030rpi, 15
setALS_WH
VEML6030rpi, 15
setALS_WL
VEML6030rpi, 15
SetGain
VEML6030rpi, 15
SetIntTime
VEML6030rpi, 16
setLearningRate
Fir1, 12
SetResolution
VEML6030rpi, 16
Shutdown
VEML6030rpi, 16
SIG
CppTimer.h, 19
start
CppTimer,
8
startalarm
StressController.cpp, 23
statpulse
StressController.cpp, 27
status

INDEX | 35

StressController.cpp, 27
statusfname
StressController.cpp, 27
statustxt
StressController.cpp, 28
StressController.cpp
alarm, 22
cnt, 23
config, 23
configfname, 23
configstat, 23
configstep, 23
configtxt, 24
ctr, 24
duserrest, 24
duserrun, 24
duserstress, 24
eventlogfname, 24
eventlogtxt, 24
exitfname, 24
exittxt, 25
fir, 25
init, 22
ipulse, 25
iuserrest, 25
iuserrun, 25
iuserstress, 25
main, 23
mpulse, 25
myexit, 25
pbpm, 26
pd, 26
PIN, 22
pulse, 26
restctr, 26
restT, 26
runctr, 26
runT, 26
scale, 26
session, 27
sessionbpm, 27
sessionfname, 27
sessiontxt, 27
startalarm, 23
statpulse, 27
status, 27
statusfname, 27
statustxt, 28
tbpm, 28
tempbpm, 28
userfound, 28
username, 28
usernamefname, 28
usernametxt, 28
usersfname, 28
userstxt, 29
veml6030, 29
whitefname, 29

whitetxt, 29

tbpm
StressController.cpp, 28
tempbpm
StressController.cpp, 28
timerEvent
CppTimer,
8

userfound
StressController.cpp, 28
username
StressController.cpp, 28
usernamefname
StressController.cpp, 28
usernametxt
StressController.cpp, 28
usersfname
StressController.cpp, 28
userstxt
StressController.cpp, 29

veml6030
StressController.cpp, 29
VEML6030rpi, 13 ∼VEML6030rpi, 13

als, 16
AutoSet, 14
Gain2Bits, 14
getALS, 14
getALS_INT, 14
getWhite, 14
init, 14
IntTime2Bits, 15
lux, 16
PowerOn, 15
powerSaving, 15
resolution, 16
setALS, 15
setALS_WH, 15
setALS_WL, 15
SetGain, 15
SetIntTime, 16
SetResolution, 16
Shutdown, 16
VEML6030rpi, 13
white, 17
whitelux, 17
VEML6030rpi.cpp
_ADR, 30
ALS_CMD, 30
ALS_CONF, 30
ALS_INT, 30
ALS_WH, 30
ALS_WL, 31
GAIN_1, 31
GAIN_1_4, 31
GAIN_1_8, 31
GAIN_2, 31

### 36 INDEX

IT100, 31
IT200, 31
IT25, 31
IT400, 32
IT50, 32
IT800, 32
PWR_SVG, 32
WHITE_CMD, 32

white
VEML6030rpi, 17
WHITE_CMD
VEML6030rpi.cpp, 32
whitefname
StressController.cpp, 29
whitelux
VEML6030rpi, 17
whitetxt
StressController.cpp, 29

zeroCoeff
Fir1, 12

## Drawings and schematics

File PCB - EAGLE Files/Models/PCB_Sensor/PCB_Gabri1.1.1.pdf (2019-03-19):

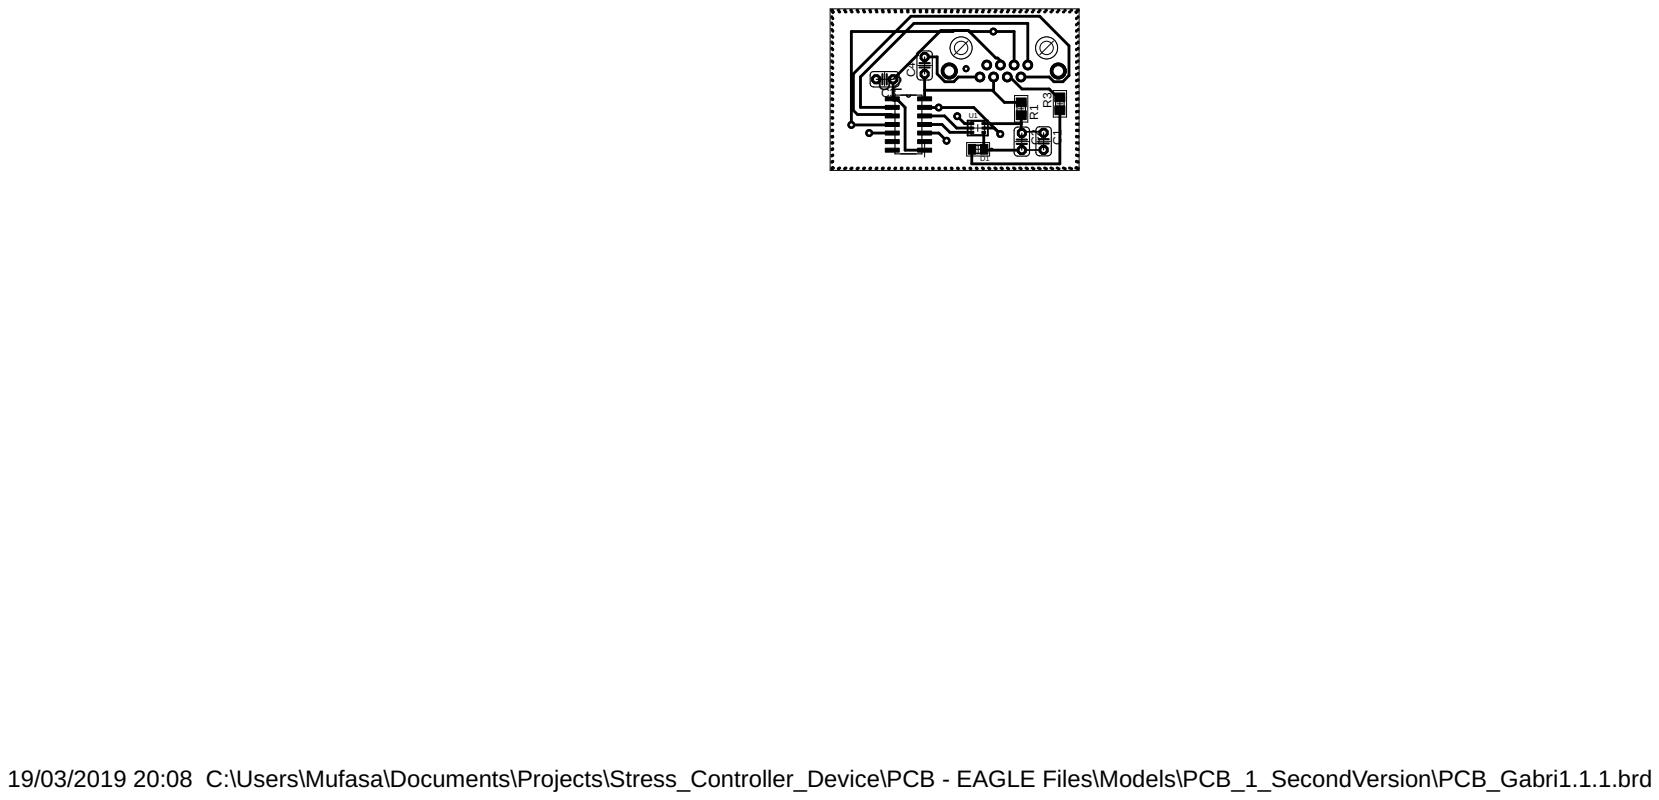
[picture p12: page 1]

19/03/2019 20:08 C:\Users\Mufasa\Documents\Projects\Stress_Controller_Device\PCB - EAGLE Files\Models\PCB_1_SecondVersion\PCB_Gabri1.1.1.brd

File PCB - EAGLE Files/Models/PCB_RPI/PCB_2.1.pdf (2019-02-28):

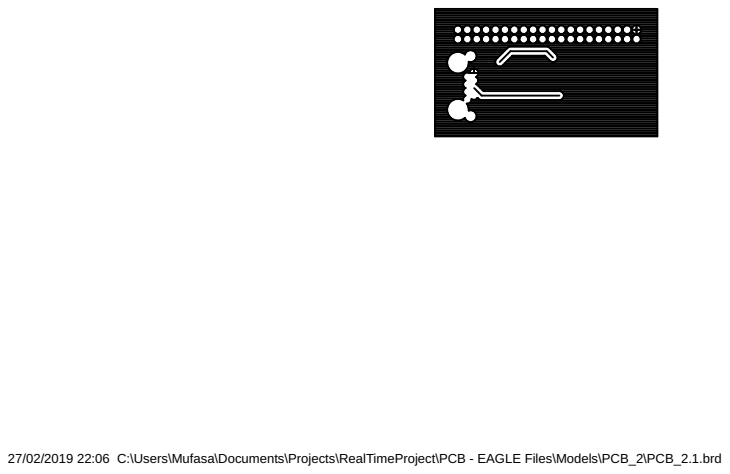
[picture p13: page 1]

27/02/2019 22:06 C:\Users\Mufasa\Documents\Projects\RealTimeProject\PCB - EAGLE Files\Models\PCB_2\PCB_2.1.brd

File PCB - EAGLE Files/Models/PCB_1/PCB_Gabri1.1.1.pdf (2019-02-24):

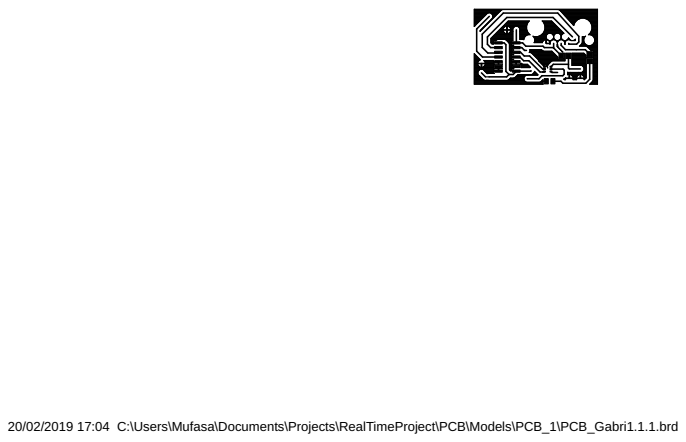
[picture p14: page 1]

20/02/2019 17:04 C:\Users\Mufasa\Documents\Projects\RealTimeProject\PCB\Models\PCB_1\PCB_Gabri1.1.1.brd

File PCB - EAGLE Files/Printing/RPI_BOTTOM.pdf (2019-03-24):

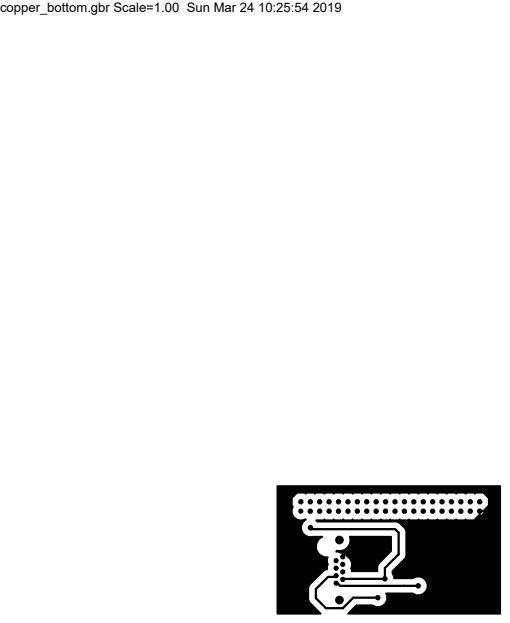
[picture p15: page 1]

copper_bottom.gbr Scale=1.00 Sun Mar 24 10:25:54 2019

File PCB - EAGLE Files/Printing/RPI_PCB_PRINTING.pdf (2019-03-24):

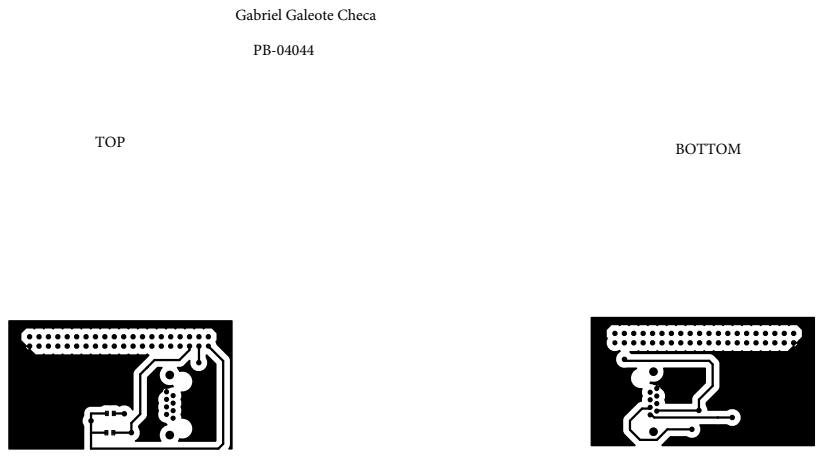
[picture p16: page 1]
TOP; BOTTOM

Gabriel Galeote Checa

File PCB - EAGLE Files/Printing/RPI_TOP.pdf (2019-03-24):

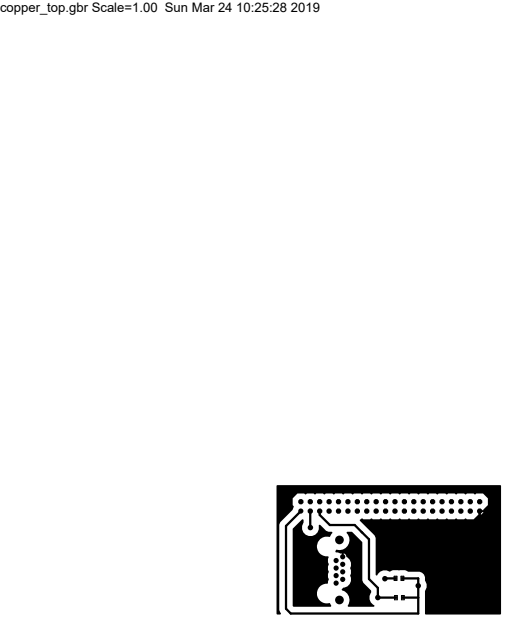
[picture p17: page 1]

copper_top.gbr Scale=1.00 Sun Mar 24 10:25:28 2019

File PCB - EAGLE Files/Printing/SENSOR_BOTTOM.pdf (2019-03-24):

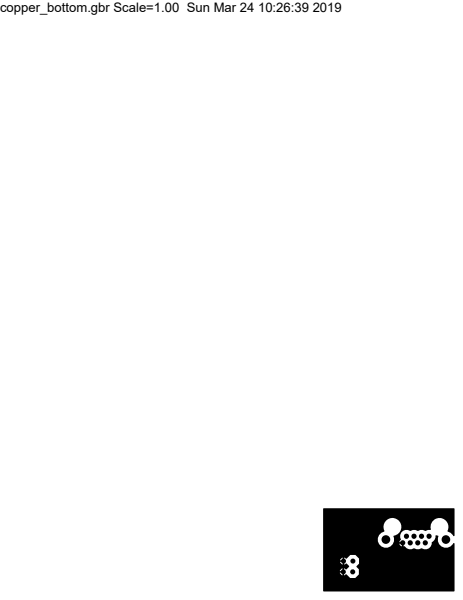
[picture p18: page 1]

copper_bottom.gbr Scale=1.00 Sun Mar 24 10:26:39 2019

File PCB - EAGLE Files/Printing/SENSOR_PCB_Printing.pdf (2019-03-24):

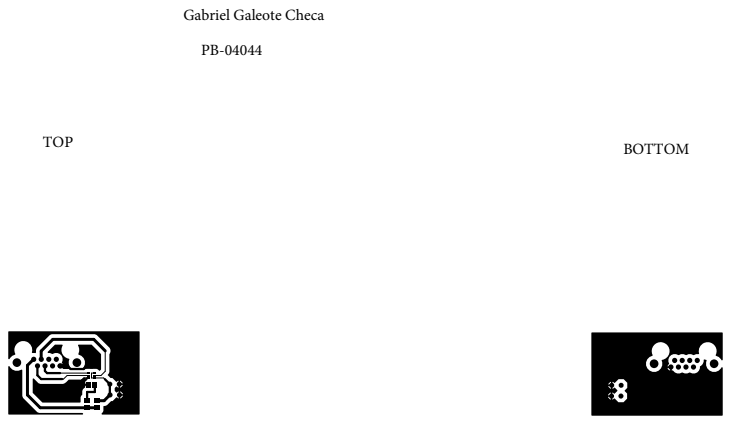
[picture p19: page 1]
TOP; BOTTOM

Gabriel Galeote Checa

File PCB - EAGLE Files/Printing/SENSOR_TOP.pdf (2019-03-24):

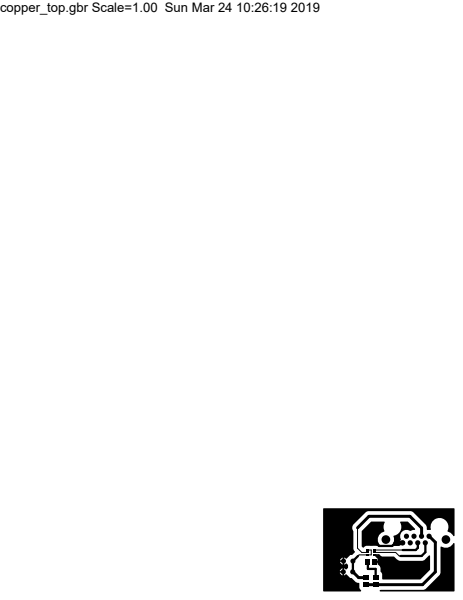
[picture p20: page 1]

copper_top.gbr Scale=1.00 Sun Mar 24 10:26:19 2019

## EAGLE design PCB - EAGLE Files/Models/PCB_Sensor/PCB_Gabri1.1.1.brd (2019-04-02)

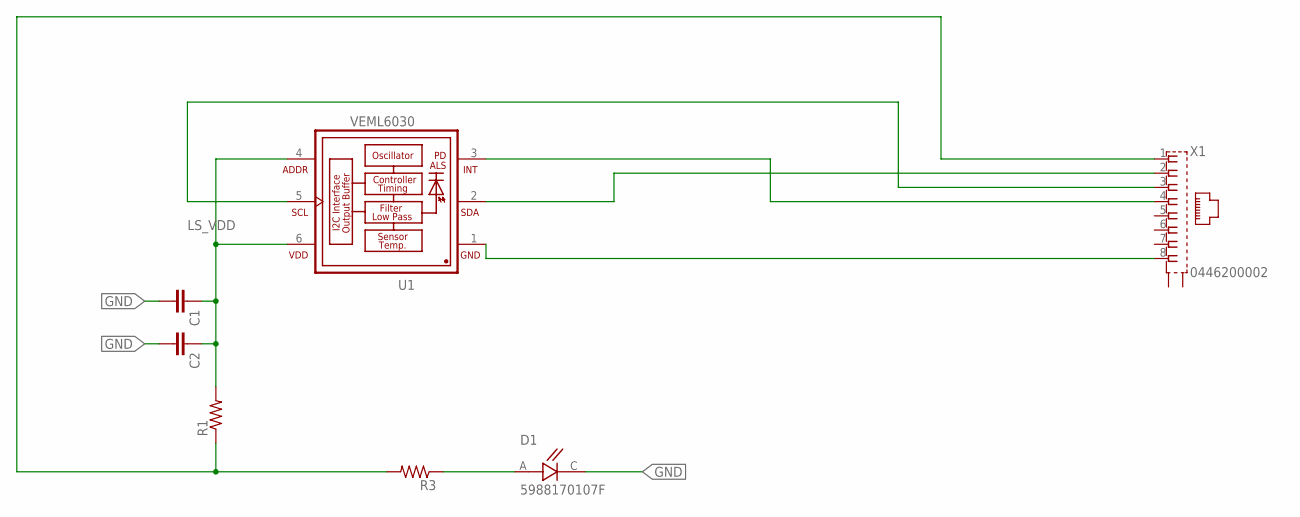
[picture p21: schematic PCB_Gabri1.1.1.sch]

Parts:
C1, C2: C-EU025-024X044; C025-024X044
D1: 5988170107F; LEDC2012X70N
R1, R3: R-US_R0805; R0805
U1: VEML6030; VISHAY_VEML6030_2X2X0.87
X1: 0446200002

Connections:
3V3: R1.1, R3.2, X1.1
GND: C1.2, C2.2, D1.C, U1.1 (GND), X1.8
INT: U1.3 (INT), X1.4
LS_VDD: C1.1, C2.1, R1.2, U1.4 (ADDR), U1.6 (VDD)
unnamed: D1.A, R3.1
SCL: U1.5 (SCL), X1.3
SDA: U1.2 (SDA), X1.2

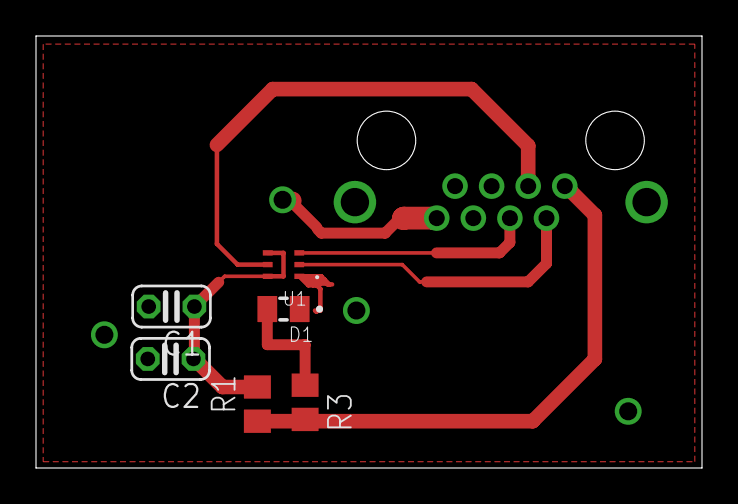
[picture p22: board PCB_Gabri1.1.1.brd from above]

Board: 2 copper layers, 37.0 x 24.0 mm, 7 parts (1 on the bottom side), 7 nets.

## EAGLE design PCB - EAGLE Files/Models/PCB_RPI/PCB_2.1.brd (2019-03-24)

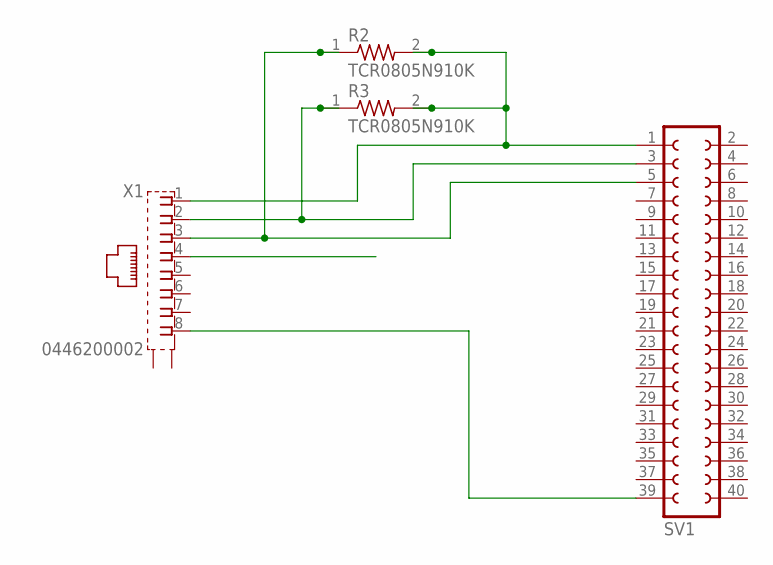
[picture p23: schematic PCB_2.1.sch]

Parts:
R2, R3: TCR0805N910K; RESC2012X65N
SV1: FE20-2
X1: 0446200002

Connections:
3V3: R2.2, R3.2, SV1.1, X1.1
GND: SV1.39, X1.8
SCL: R2.1, SV1.5, X1.3
SDA: R3.1, SV1.3, X1.2

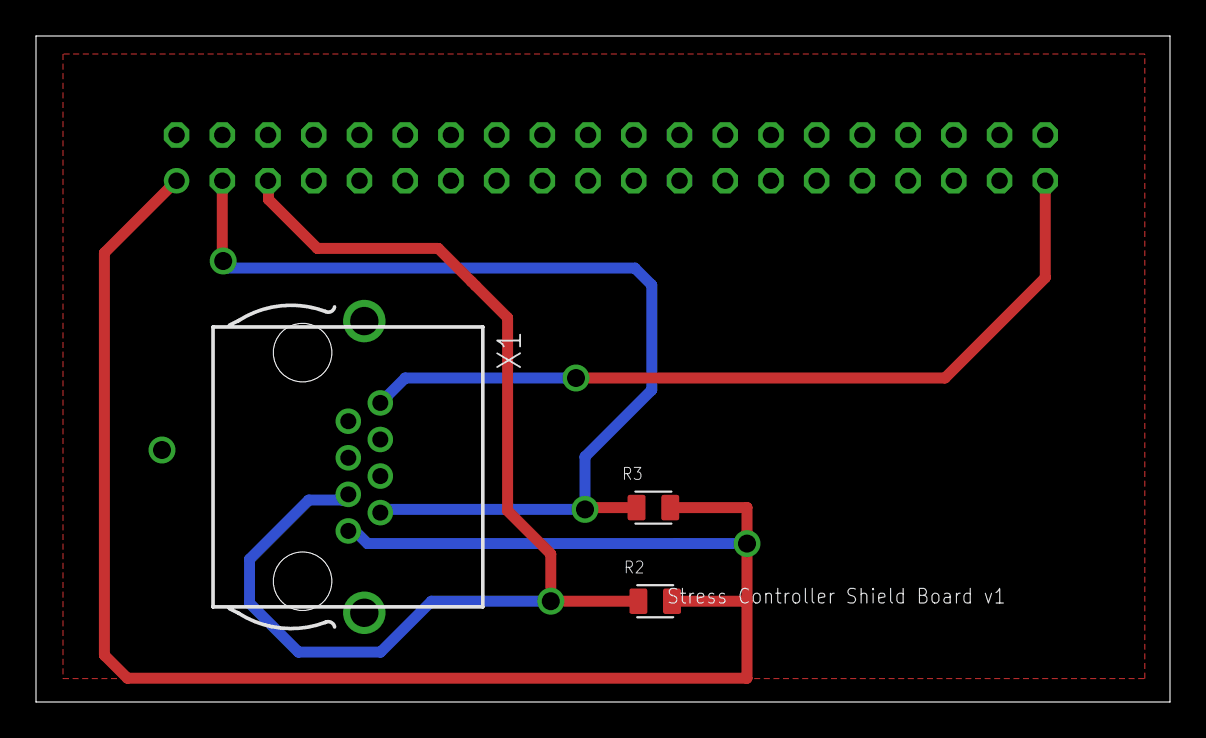
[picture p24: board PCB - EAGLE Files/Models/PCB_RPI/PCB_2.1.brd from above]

Board: 2 copper layers, 63.0 x 37.0 mm, 4 parts (1 on the bottom side), 4 nets.

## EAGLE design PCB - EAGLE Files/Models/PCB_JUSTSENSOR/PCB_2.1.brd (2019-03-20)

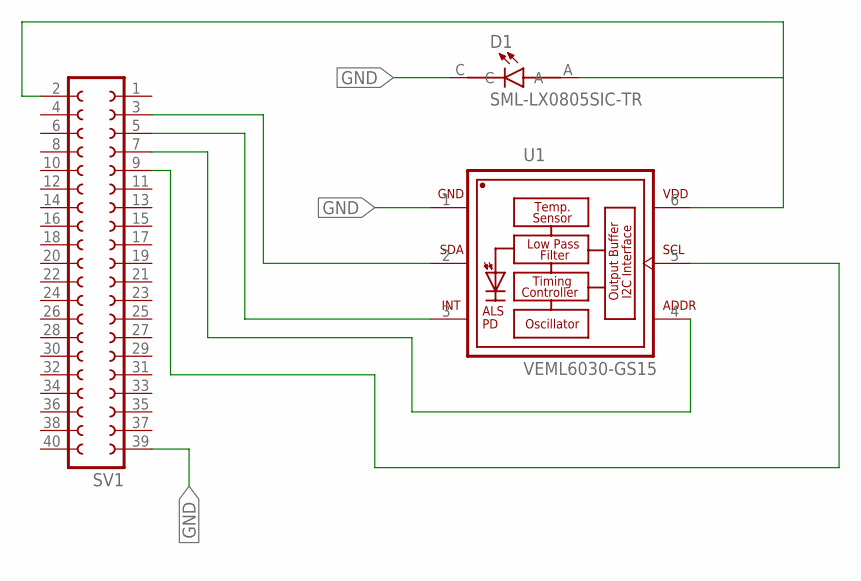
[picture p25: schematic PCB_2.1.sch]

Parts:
D1: SML-LX0805SIC-TR; LEDC2012X120N
SV1: FE20-2
U1: VEML6030-GS15; VISHAY_VEML6030_2X2X0.87

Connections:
GND: D1.C, SV1.39, U1.1 (GND)
unnamed: SV1.3, U1.2 (SDA)
unnamed: SV1.5, U1.3 (INT)
unnamed: SV1.9, U1.5 (SCL)
unnamed: SV1.7, U1.4 (ADDR)
VCCB: D1.A, SV1.2, U1.6 (VDD)

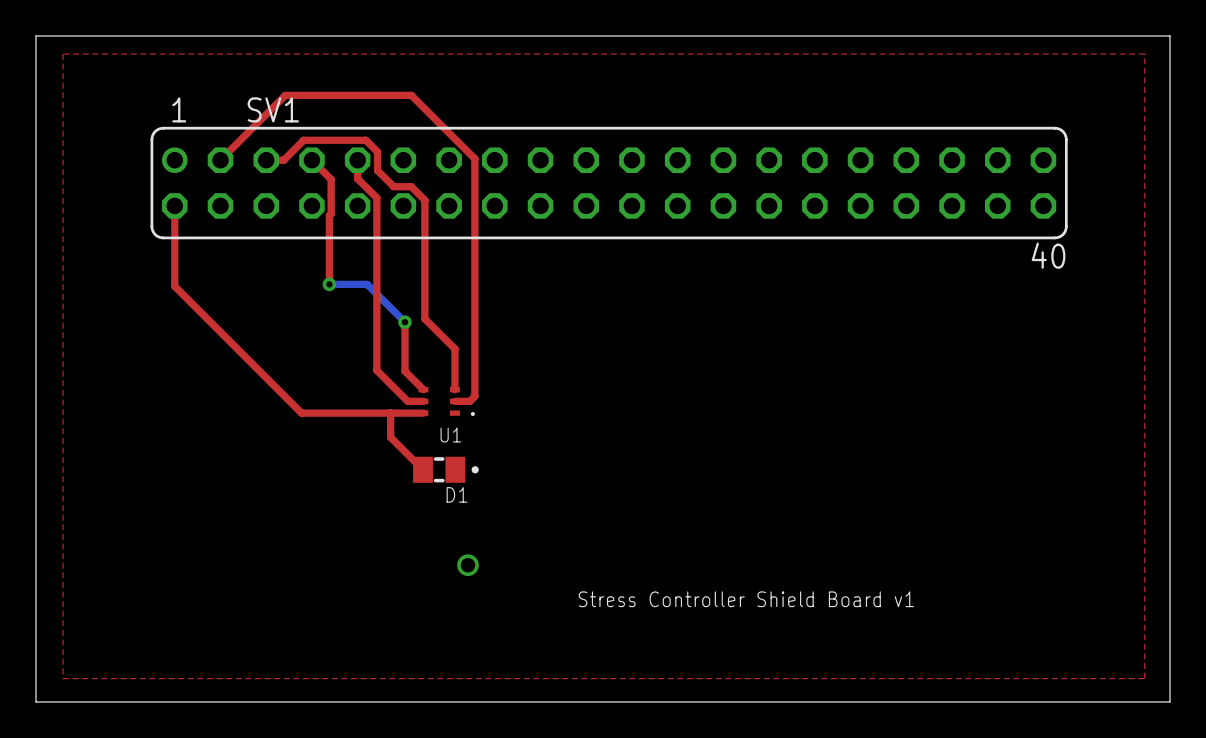
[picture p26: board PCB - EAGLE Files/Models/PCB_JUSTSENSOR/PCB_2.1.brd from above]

Board: 2 copper layers, 63.0 x 37.0 mm, 3 parts (0 on the bottom side), 6 nets.

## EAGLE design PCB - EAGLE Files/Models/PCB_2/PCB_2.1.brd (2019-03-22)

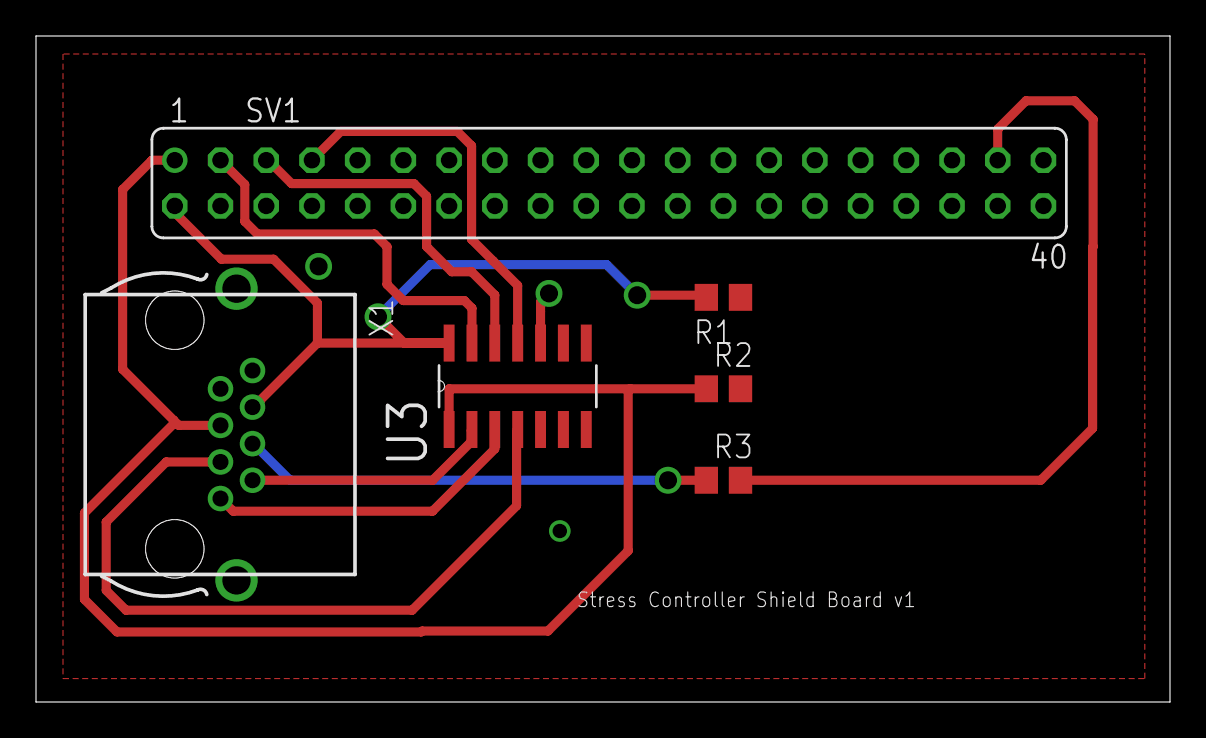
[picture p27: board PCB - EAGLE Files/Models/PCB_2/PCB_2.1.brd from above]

Board: 2 copper layers, 63.0 x 37.0 mm, 6 parts (0 on the bottom side), 11 nets.

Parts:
R1, R2, R3: R0805
SV1: FE20-2
U3: TXS0104ED; SOIC127P600X175-14N
X1: 0446200002

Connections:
A1: U3.2, X1.2
A2: U3.3, X1.1
A3: U3.4, X1.3
GND: R1.1, R2.2, SV1.39, U3.5, U3.7, U3.10, X1.8
INT: SV1.7, U3.11
LED: R3.1, X1.4
unnamed: R3.2, SV1.37
SCL: SV1.5, U3.12
SDA: SV1.3, U3.13
VCCA: R2.1, SV1.1, U3.1, X1.5
VCCB: R1.2, SV1.2, U3.14, X1.6

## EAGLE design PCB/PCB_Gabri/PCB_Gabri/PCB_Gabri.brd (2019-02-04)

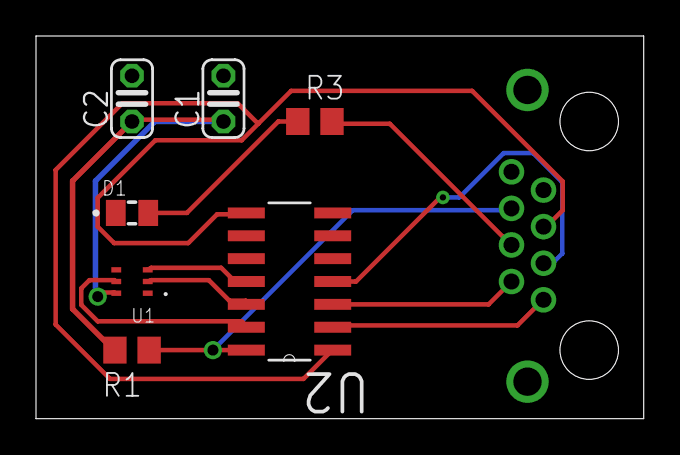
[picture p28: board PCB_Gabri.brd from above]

Board: 2 copper layers, 33.8 x 21.3 mm, 8 parts (1 on the bottom side), 11 nets.

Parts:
C1, C2: C025-024X044
D1: 5988170107F; LEDC2012X70N
R1, R3: R0805
U1: VEML6030; VISHAY_VEML6030_2X2X0.87
U2: TXS0104ED; SOIC127P600X175-14N
X1: 0446200002

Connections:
LED_1: R3.2, X1.4
LED_2: D1.A, R3.1
unnamed: U1.5, U2.13
unnamed: U1.3, U2.11
unnamed: U1.2, U2.12
unnamed: U2.2, X1.1
unnamed: U2.3, X1.2
unnamed: U2.4, X1.3
unnamed: R1.1, U2.14, X1.6
unnamed: U2.1, U2.8, X1.5
S$2: C1.1, C2.1

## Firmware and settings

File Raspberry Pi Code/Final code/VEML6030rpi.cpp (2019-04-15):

/**
 *
 * "Library to use VEML6030 light sensor with RPI"
 * University of Glasgow
 * Supervised by: Bernd Porr
 * By Ahmed Elmogamer, Daewon Jung and Gabriel Galeote Checa
 *
 *
 * Has been further developed from and inspired by:
 *  for mbed microcontroller: https://os.mbed.com/teams/MSS/code/VEML6030/
 *  for Arduino, Bobby Schulz @ Northern Widget LLC: https://github.com/NorthernWidget/VEML6030
 *
 *
 * Official project location:
 * https://github.com/GGChe/Stress_Controller_Device
 *
 * Open Readme for details about the project
 *
 * -----------------------------------------------------------------
 *
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
 * THE SOFTWARE IS PROVIDED "AS IS", WITHOUT WARRANTY OF ANY KIND, EXPRESS OR
 * IMPLIED, INCLUDING BUT NOT LIMITED TO THE WARRANTIES OF MERCHANTABILITY,
 * FITNESS FOR A PARTICULAR PURPOSE AND NONINFRINGEMENT. IN NO EVENT SHALL THE
 * AUTHORS OR COPYRIGHT HOLDERS BE LIABLE FOR ANY CLAIM, DAMAGES OR OTHER
 * LIABILITY, WHETHER IN AN ACTION OF CONTRACT, TORT OR OTHERWISE, ARISING FROM,
 * OUT OF OR IN CONNECTION WITH THE SOFTWARE OR THE USE OR OTHER DEALINGS IN
 * THE SOFTWARE.
 **/

#include "VEML6030rpi.h"
#include <wiringPiI2C.h>
#include <fstream>
#include <math.h>
#include <iostream>
using namespace std;

//Registers
#define _ADR        0x48
#define ALS_CONF  	0x00
#define ALS_WH      0x01
#define ALS_WL      0x02
#define PWR_SVG     0x03
#define ALS_CMD     0x04
#define WHITE_CMD   0x05
#define ALS_INT     0x06

//Integration Times bit masks
#define IT25  0x300  //25ms
#define IT50  0x200  //50ms
#define IT100 0x000 //100ms
#define IT200 0x040 //200ms
#define IT400 0x080 //400ms
#define IT800 0x0C0 //800ms

//Gains
#define GAIN_1 0x0000 //Gain x1
#define GAIN_2 0x0800 //Gain x2
#define GAIN_1_8 0x1000 //Gain x1/8
#define GAIN_1_4 0x1800 //Gain x1/4

VEML6030rpi::VEML6030rpi(){

}
VEML6030rpi::~VEML6030rpi(){
}
void VEML6030rpi::init(uint8_t ADR){
  //Setting up I2C
  I2CRW = wiringPiI2CSetup(0x48);
  if(I2CRW <0){
  cout<<"set up failed"<<endl;}

  //Writing to Register 00 0x0000
  uint8_t dByteW[3] = {0x00, 0x00, 0x00};
  writeVEML(dByteW, 3);
}
void VEML6030rpi::setALS(uint16_t cmd){
  //Data Byte Write
  uint8_t dByteW[3];
  //Register
  dByteW[0] = ALS_CONF ;
  //command to be written to the register
  dByteW[1] = cmd & 0xFF ;
  dByteW[2] = (cmd >> 8) & 0xFF ;
  writeVEML(dByteW, 3) ;
}
void VEML6030rpi::setALS_WH(uint16_t wh){
  //Data Byte Write
  uint8_t dByteW[3];
  //Register
  dByteW[0] = ALS_WH ;
  //command to be written to the register
  dByteW[1] = wh & 0xFF ;
  dByteW[2] = (wh >> 8) & 0xFF ;
  writeVEML(dByteW, 3) ;
}
void VEML6030rpi::setALS_WL(uint16_t wl){
  //Data Byte Write
  uint8_t dByteW[3];
  //Register
  dByteW[0] = ALS_WL ;
  //command to be written to the register
  dByteW[1] = wl & 0xFF ;
  dByteW[2] = (wl >> 8) & 0xFF ;
  writeVEML(dByteW, 3) ;
}
uint8_t VEML6030rpi::SetIntTime(uint16_t TimeBits){
  //Register
  uint8_t cmd = ALS_CONF;
  //Data Byte Read
  uint8_t dByteR[2];
  //Update global config value
  readVEML(cmd, dByteR, 2) ;
  //Data Byte Write
  uint8_t dByteW[3];
  //cout<<(int)TimeBits<<endl;
  dByteW[0] = ALS_CONF;
  //command to be written to the register
  dByteW[1] = (TimeBits & 0xFF) | dByteR[0];
  dByteW[2] = ((TimeBits >> 8) & 0xFF) | dByteR[1];
	writeVEML(dByteW , 3);
}
uint8_t VEML6030rpi::SetGain(uint16_t GainVal){
  //Register
  uint8_t cmd = ALS_CONF;
  //Data Byte Read
  uint8_t dByteR[2];
  //Update global config value
  readVEML(cmd, dByteR, 2) ;
  //Data Byte Write
  uint8_t dByteW[3];
  dByteW[0] = ALS_CONF;
  //command to be written to the register
  dByteW[1] = (GainVal & 0xFF) | dByteR[0];
  dByteW[2] = ((GainVal >> 8) & 0xFF) | dByteR[1];
	writeVEML(dByteW , 3);
}
uint16_t VEML6030rpi::getALS(void){
  uint16_t als = 0 ;
  //Register
  uint8_t cmd = ALS_CMD ;
  //Data Byte Read
  uint8_t dByteR[2];
  readVEML(cmd, dByteR, 2) ;
  als = (dByteR[1] << 8) | dByteR[0] ;
  return ( als ) ;
}
uint16_t VEML6030rpi::getWhite(void){
  uint16_t wh = 0 ;
  //Register
  uint8_t cmd = WHITE_CMD ;
  //Data Byte Read
  uint8_t dByteR[2];
  readVEML(cmd, dByteR, 2) ;
  wh = (dByteR[1] << 8) | dByteR[0] ;
  return ( wh ) ;
}
uint16_t VEML6030rpi::getALS_INT(void){
  uint16_t als_int = 0 ;
  //Register
  uint8_t cmd = ALS_INT ;
  //Data Byte Read
  uint8_t dByteR[2];
  readVEML(cmd, dByteR, 2) ;
  als_int = (dByteR[1] << 8) | dByteR[0] ;
  return ( als_int ) ;
}
unsigned int VEML6030rpi::IntTime2Bits(unsigned int Time){
  //Calculations of bits to change from int to bits
	uint8_t X2X1 = (int)(log(Time/100)/log(2));
	uint8_t X4X3 = (int)(((Time % 100) / 25) + 2*(Time % 50)/25);
	return ((X4X3 << 2) | (X2X1)) << 6;
}
uint16_t VEML6030rpi::Gain2Bits(float GainVal){
  //Changing of float gain values to bits
  float Gains[4] = {0.125, 0.25, 1, 2};
  unsigned int GainsInBits[4] = {0x1000, 0x1800, 0x0000, 0x0800};
	for(int i = 0; i < 4; i++){  //Use linear search to avoid float math and increase speed
		if(Gains[i] == GainVal){
			return (GainsInBits[i]); //if entries match, return bits
			break;
		}
	}
	return 0x1000; //Return gain of 1/8 if not a valid gain value
}
void VEML6030rpi::powerSaving(uint16_t ps){
  //Data Byte Write
  uint8_t dByteW[3];
  //Register
  dByteW[0] = PWR_SVG ;
  //command to be written to the register
  dByteW[1] = ps & 0xFF ;
  dByteW[2] = (ps >> 8) & 0xFF ;
  writeVEML(dByteW, 3) ;
}
uint8_t VEML6030rpi::Shutdown(void){ //Places device in shutdown low power mode
  //Data Byte Read
  uint8_t dByteR[2];
  //Register
  uint8_t cmd = ALS_CONF;
  readVEML(cmd, dByteR, 2) ;
  //Data Byte Write
  uint8_t dByteW[3];
  dByteW[0] = cmd;
  //command to be written to the register
  dByteW[1] = dByteR[0] | 0x01;
  dByteW[2] = dByteR[1] | 0x00;
  writeVEML(dByteW , 3);
}
uint8_t VEML6030rpi::PowerOn(void){ //Turns device on from shutdown mode
  //Data Byte Read
  uint8_t dByteR[2];
  //Register
  uint8_t cmd = ALS_CONF;
  readVEML(cmd, dByteR, 2) ;
  //Data Byte Write
  uint8_t dByteW[3];
  dByteW[0] = cmd;
    //command to be written to the register
  dByteW[1] = dByteR[0] & 0xFE;
  dByteW[2] = dByteR[1] & 0xFF;
  writeVEML(dByteW , 3);
}
void VEML6030rpi::SetResolution(float Gain, float IntTime){//Add non-linear correction!
  resolution = (1.8432/((float)IntTime/25.0))*(0.125/Gain);
}
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

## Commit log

2019-01-28 Create PCB DESIGN
2019-02-03 This is the PCB I have made, check it oiu
    [PCB_1.1.sch, PCB_1.sch, PCB_2.1.brd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]
2019-02-06 Modification of the management
    [PCB_2.1.brd, PCB_2.1.sch]
2019-02-06 LAB 06022019
    [PCB_1.sch, PCB_2.1.brd, PCB_2.1.sch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]
2019-02-09 Changes for the PCB
    [PCB_2.1.brd, PCB_2.1.sch]
2019-02-10 Uploaded the ZIP of the PCB
2019-02-11 Tiding up the documents
    [BOTTOM CASE.SLDPRT, PCB_2.1.brd, PCB_2.1.sch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]
2019-02-13 PCB drawings
    [PCB_Gabri1.1.1.brd, PCB_Gabri1.1.1.sch, PCB_Gabri1.1.brd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]
2019-02-17 just a few changes
    [PCB_2.1.brd, PCB_2.1.sch, PCB_Gabri1.1.1.brd]
2019-02-24 Organising some documents and folders
    [BOTTOM CASE new.x_t, BOTTOM CASE.SLDPRT, PCB_2.1.brd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]
2019-02-28 Updating PCB printings
    [PCB_2.1.brd, PCB_Gabri1.1.1.brd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]
2019-02-28 Uploaded the final version of the PCB
    [PCB_Gabri1.1.1_v2.brd, PCB_Gabri1.1.1_v2.sch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]
2019-02-28 Create PCB case
2019-03-06 Uploading gerber files
    [PCB_2.1.brd]
2019-03-06 Rearrange some folders
    [PCB_Gabri1.1.1.brd, PCB_Gabri1.1.1.sch, PCB_Gabri1.1.brd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]
2019-03-13 Uploaded thefinal printing documents of the PCB
2019-03-15 Added a possible test for the LED
2019-03-22 PCB design
2019-03-24 Final Version PCB
    [PCB_2.1.brd, PCB_2.1.sch, PCB_Gabri1.1.1.brd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]
2019-03-24 Uploaded printings of final version pcb
    [PCB_2.1.brd, PCB_2.1.sch, PCB_Gabri1.1.1.brd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]
2019-03-24 Document Organisation
    [BOTTOM CASE new.x_t, BOTTOM CASE.SLDPRT, TOP CASE new.SLDPRT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]
2019-04-02 Testing readme
    [PCB_Gabri1.1.1.brd]
2019-04-05 update repository
    [PCB_2.1.brd, PCB_2.1.sch, PCB_Gabri1.1.1.brd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]
2019-04-11 Final code uploaded
    [PCB_Gabri1.1.1.brd, PCB_Gabri1.1.1.sch, config.txt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]
2019-04-15 A Few Documentation changes
    [PCB_Gabri1.1.1.brd, PCB_Gabri1.1.1.sch, config.txt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]
